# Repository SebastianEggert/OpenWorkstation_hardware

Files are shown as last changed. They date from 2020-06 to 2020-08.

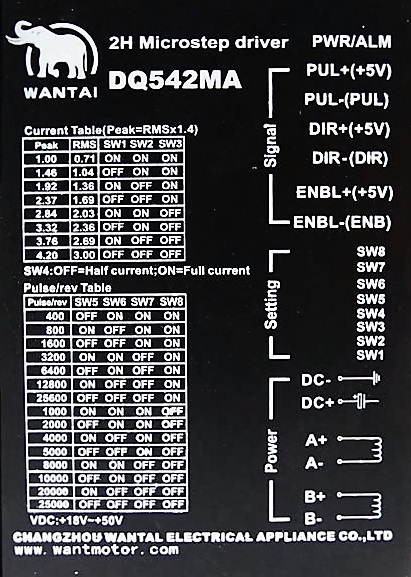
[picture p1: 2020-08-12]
OpenBuilds/SW2014 Parts Library 1/6 - Electronics/Decals/dq540ma_jpg.jpg

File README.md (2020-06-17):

## Hardware

The hardware section is divided into CAD files (SolidWorks) used to build the presented workstation (incl modules) and a parts library to accelerate the development process for new modules in the future.

All hardware files are available for the presented workstation:

 * [Assembled workstation](workstation)
 * [Pipetting module](modulePipetting)  
 * [Crosslinker module](moduleCrosslinker)
 * [Storage module](moduleStorage)
 * [Transport module](moduleTransport)
 * [Base frame](base-frame)

The following libraries are available to support users during the development of new module:

 * [Aluminium profiles](aluminium-profiles)
 * [Module frames](moduleFrame)
 * [OpenBuilds parts](OpenBuilds)

OpenBuilds provides additional support via their [SolidWorks part library](https://openbuilds.com/projectresources/solidworks-2014-parts-library.160/) and the uploaded models on [GrabCAD](https://grabcad.com/openbuilds-1/models).

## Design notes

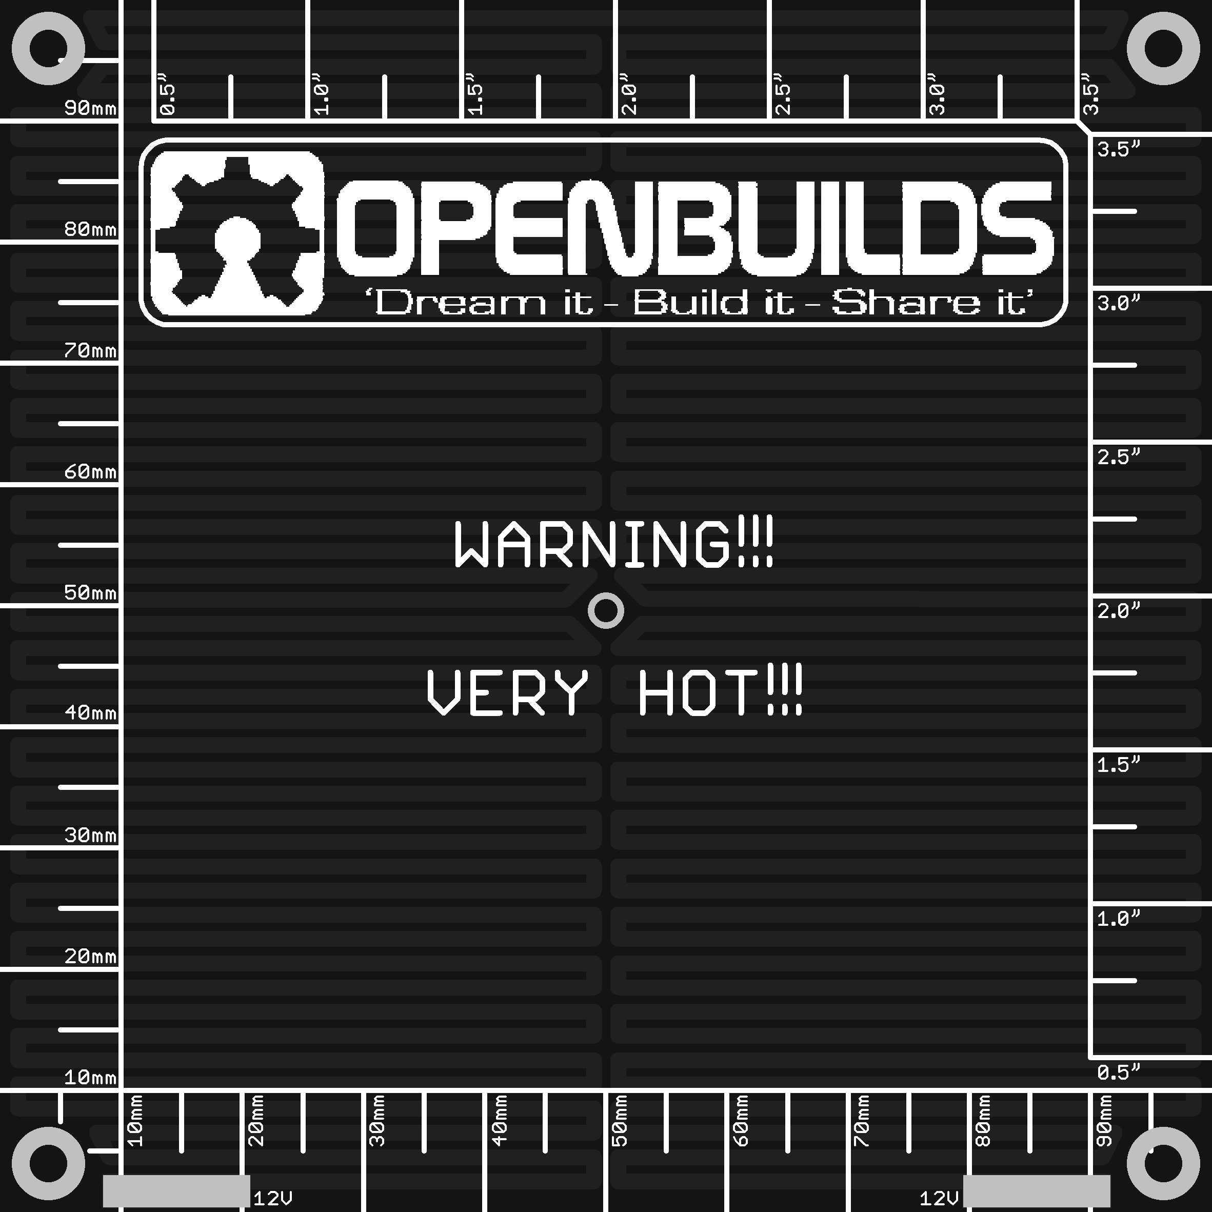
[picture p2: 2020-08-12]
OpenBuilds/SW2014 Parts Library 1/6 - Electronics/Decals/eagleUp_incendi_top_board.png

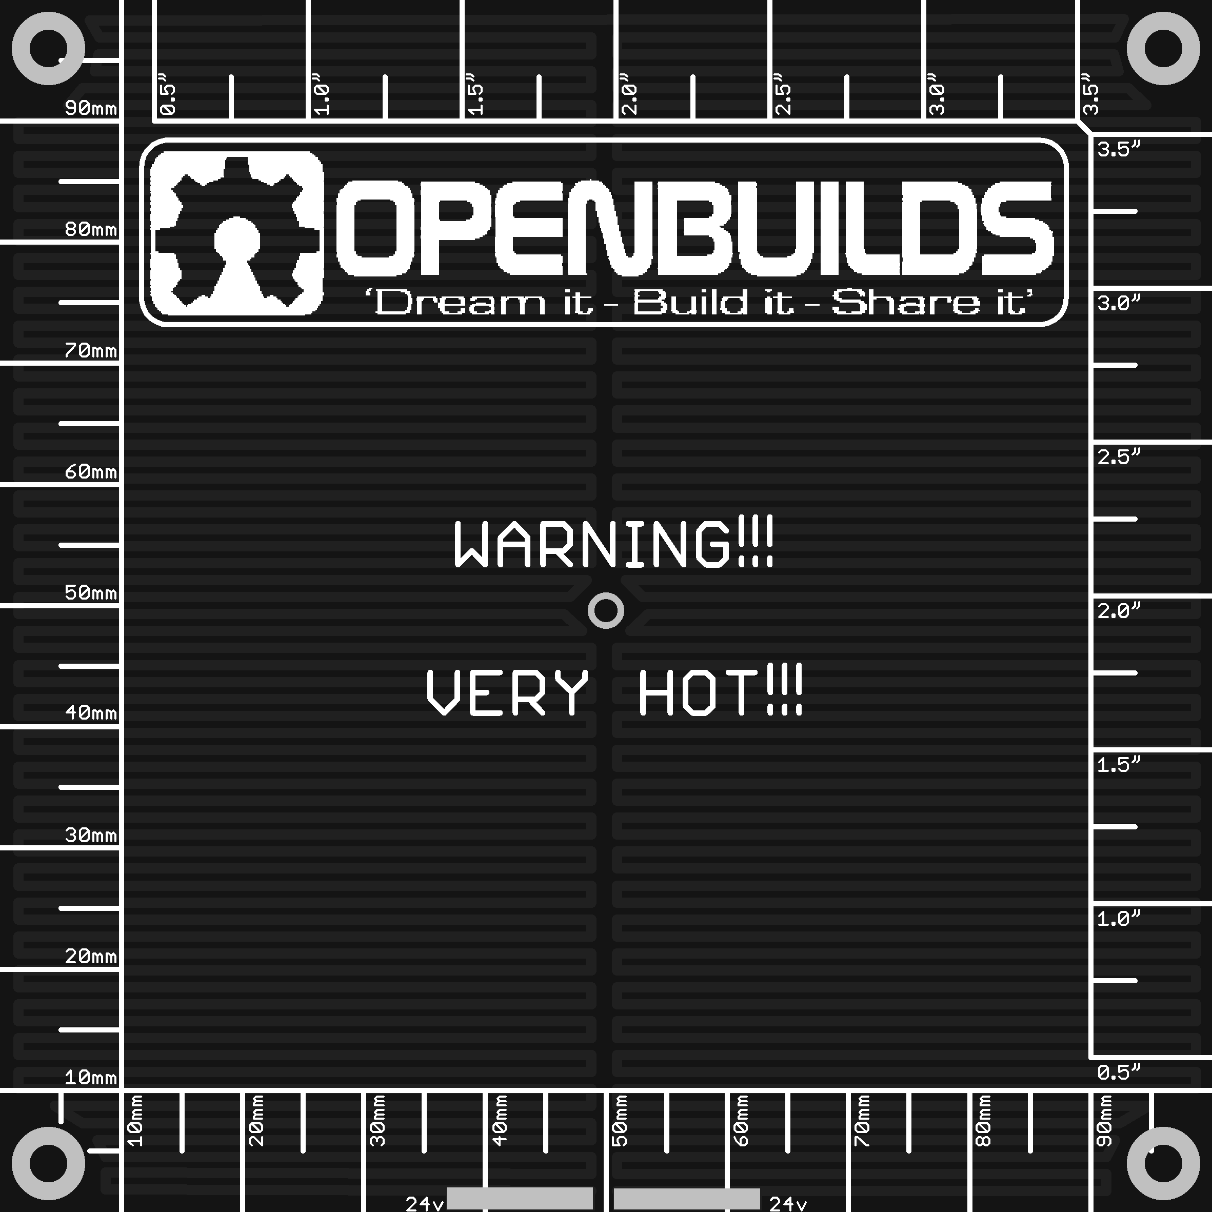
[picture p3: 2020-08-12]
OpenBuilds/SW2014 Parts Library 1/6 - Electronics/Decals/eagleUp_incendi_bottom_board.png

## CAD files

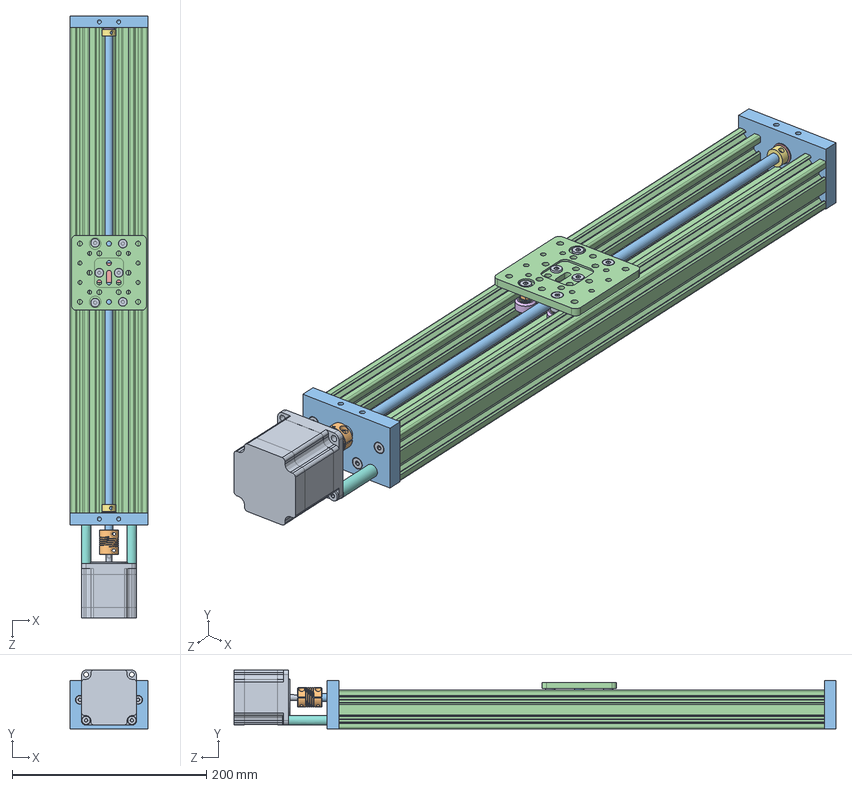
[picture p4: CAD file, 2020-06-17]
moduleCrosslinker/C-Beam_actuator_500mm.SLDASM
80.0 x 60.7 x 620.0 mm
Low Profile Screw M5 x 16
Nylon Insert Lock Nut M5 x 6
C-Beam End Mount x 2
C-Beam 40x80x500 Linear Rail
Ball Bearing 8 x 16 x 5 x 2
Shim Washer 8mm x 2
Lock Collar 8mm x 2
Aluminum Spacer 40mm x 2
Nema 23 Stepper Motor
Flexible Coupling 0.25in x 8mm
8mm leadscrew 540mm
C-Beam Gantry Plate
8mm Acme Nut Block
Xtreme Mini V Wheel x 4
Ball Bearing 5 x 10 x 4.2 x 8
Precision Shim 8 x 5 x 1 x 8
Aluminum Spacer 6mm x 2
Mini Eccentric Spacer 6mm x 2
Aluminum Spacer 3mm x 2

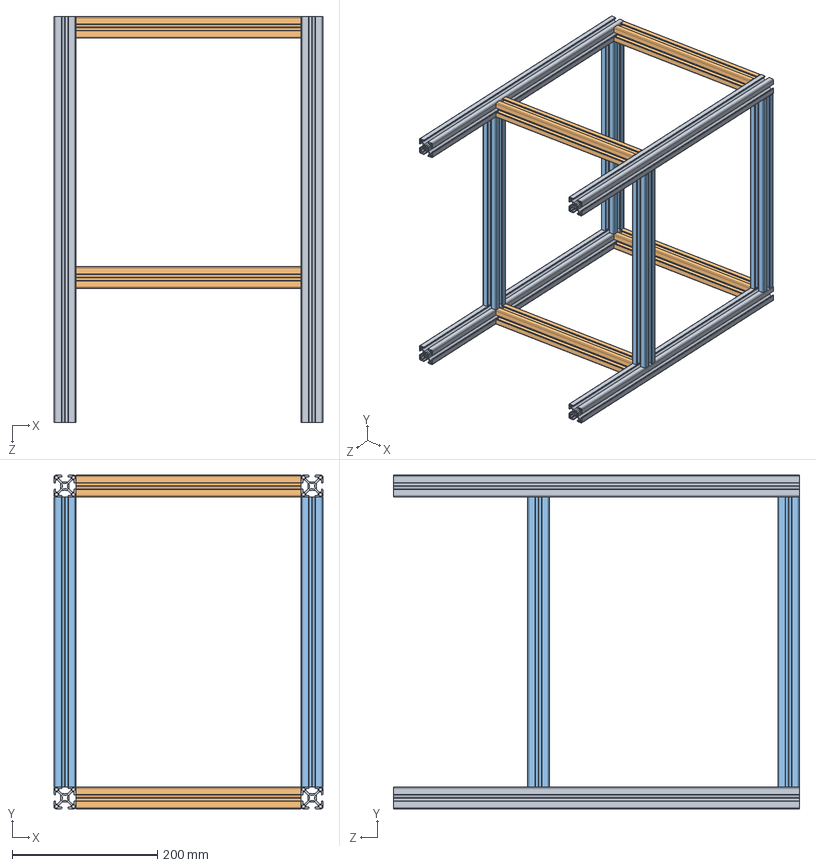
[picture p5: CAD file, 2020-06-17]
moduleFrame/module6_frame_v1.0.SLDASM
371.0 x 460.0 x 560.0 mm
profile_30x30mm_560mm x 4
Profile_30x30mm_311mm x 4
Profile_30x30mm_400mm x 4

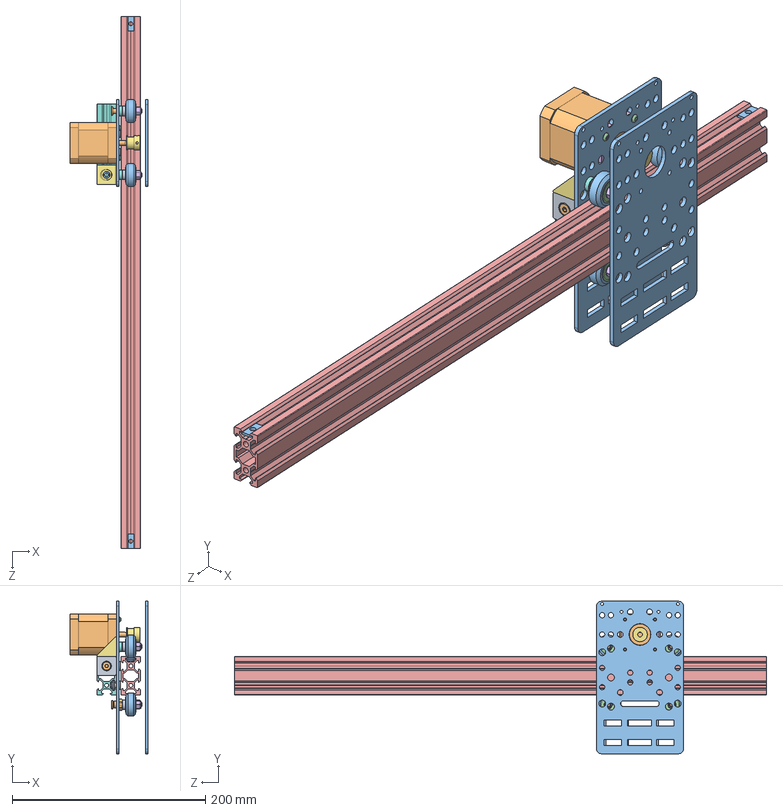
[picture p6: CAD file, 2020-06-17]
modulePipetting/Mini-V-Slot-Belt-Pinion-Actuator_550mm_v0.1.SLDASM
81.0 x 157.7 x 550.0 mm
Double Tee Nut x 2
Low Profile Screw M5 x 8
Button Head Socket Cap Screw M3 x 4
Tee Nut x 2
V-Slot 20x40x550 Linear Rail
Motor Mount Plate Nema 17
Nema 17 Stepper Motor
Solid V Wheel x 4
Ball Bearing 5 x 16 x 5 x 8
Precision Shim 10 x 5 x 1 x 4
Nylon Insert Lock Nut M5 x 4
GT2 Timing Pulley 20 Tooth
Aluminum Spacer .25in x 2
Aluminum Spacer .125in x 4
Eccentric Spacer 0.25in x 2
1002_Motor_Mount_Plate x 2

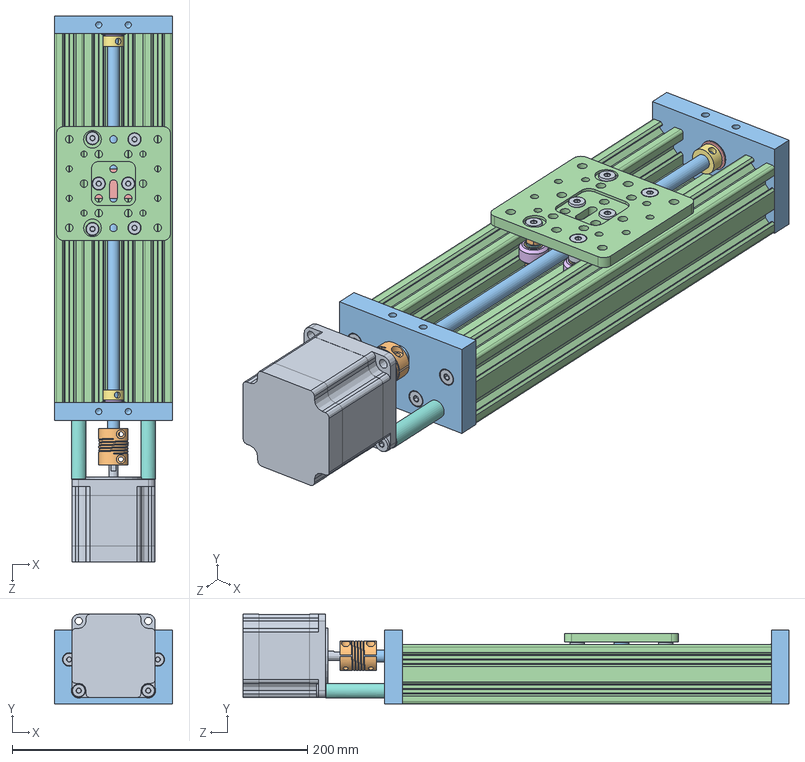
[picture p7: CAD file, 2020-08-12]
OpenBuilds/SW2014 Parts Library 1/Assemblies/C-Beam Linear Actuator/C-Beam Linear Actuator 250mm.SLDASM
80.0 x 60.7 x 370.0 mm
Low Profile Screw M5 x 16
Nylon Insert Lock Nut M5 x 6
C-Beam End Mount x 2
C-Beam 40x80x250 Linear Rail
Ball Bearing 8 x 16 x 5 x 2
Shim Washer 8mm x 2
Lock Collar 8mm x 2
Aluminum Spacer 40mm x 2
Nema 23 Stepper Motor
Flexible Coupling 0.25in x 8mm
8mm leadscrew 290mm
C-Beam Gantry Plate
8mm Acme Nut Block
Xtreme Mini V Wheel x 4
Ball Bearing 5 x 10 x 4.2 x 8
Precision Shim 8 x 5 x 1 x 8
Aluminum Spacer 6mm x 2
Mini Eccentric Spacer 6mm x 2
Aluminum Spacer 3mm x 2

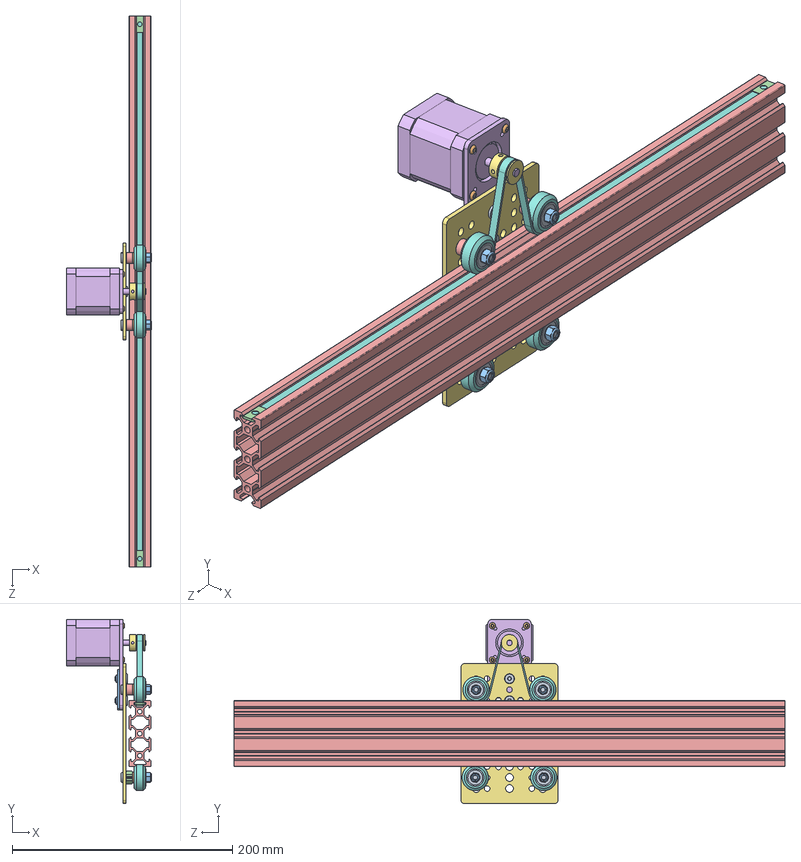
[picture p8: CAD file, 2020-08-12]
OpenBuilds/SW2014 Parts Library 1/Assemblies/V Slot Belt and Pinion Actuator/V Slot Belt and Pinion Actuator 500mm.SLDASM
77.0 x 167.2 x 500.0 mm
Low Profile Screw M5 x 6
Button Head Socket Cap Screw M3 x 4
Double Tee Nut
Tee Nut x 2
V-Slot 20x60x500 Linear Rail
Nema 17 Stepper Motor
V-Slot Gantry Plate 20-80mm
Solid V Wheel x 4
Ball Bearing 5 x 16 x 5 x 8
Precision Shim 10 x 5 x 1 x 8
Nylon Insert Lock Nut M5 x 4
Eccentric Spacer 6mm x 2
Aluminum Spacer 6mm x 2
Motor Mount Plate Nema 17
GT2 Timing Pulley 20 Tooth
GT2 Belt 585mm

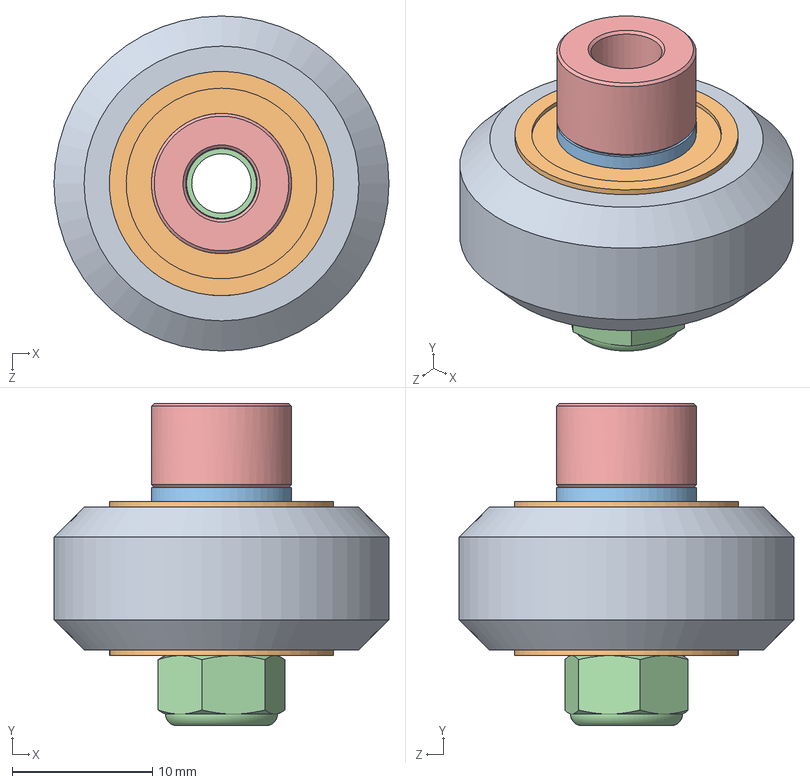
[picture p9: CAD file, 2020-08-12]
OpenBuilds/SW2014 Parts Library 1/Assemblies/Wheels/Xtreme V Wheel.SLDASM
23.9 x 23.0 x 23.9 mm
Xtreme Solid V Wheel
Ball Bearing 5 x 16 x 5 x 2
Precision Shim 10 x 5 x 1 x 2
Nylon Insert Lock Nut M5
Aluminum Spacer 6mm

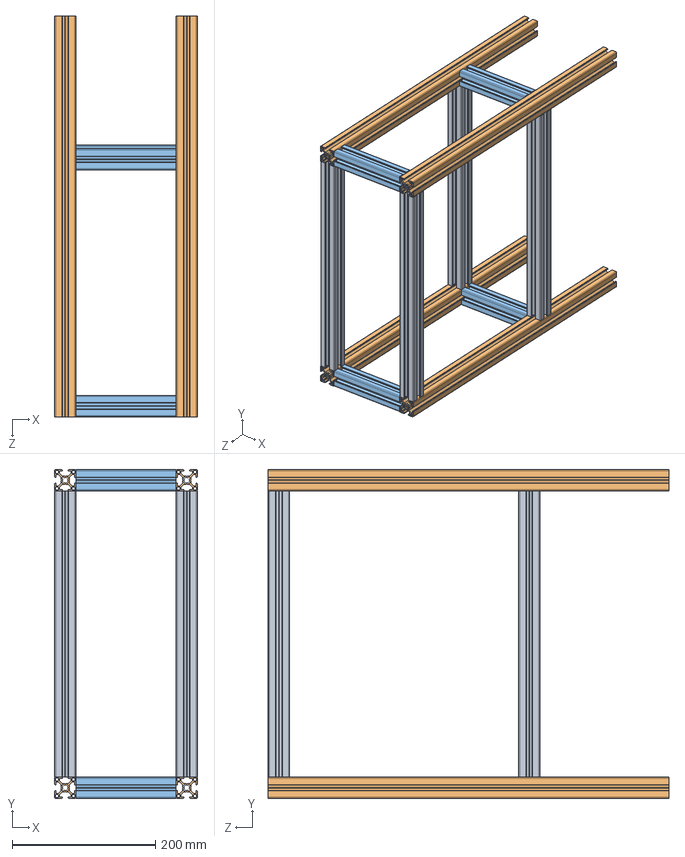
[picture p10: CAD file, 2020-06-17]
moduleFrame/module2_frame_v1.0.SLDASM
200.0 x 460.0 x 560.0 mm
Profile_30x30mm_400mm x 4
profile_30x30mm_560mm x 4
Profile_30x30mm_140mm x 4

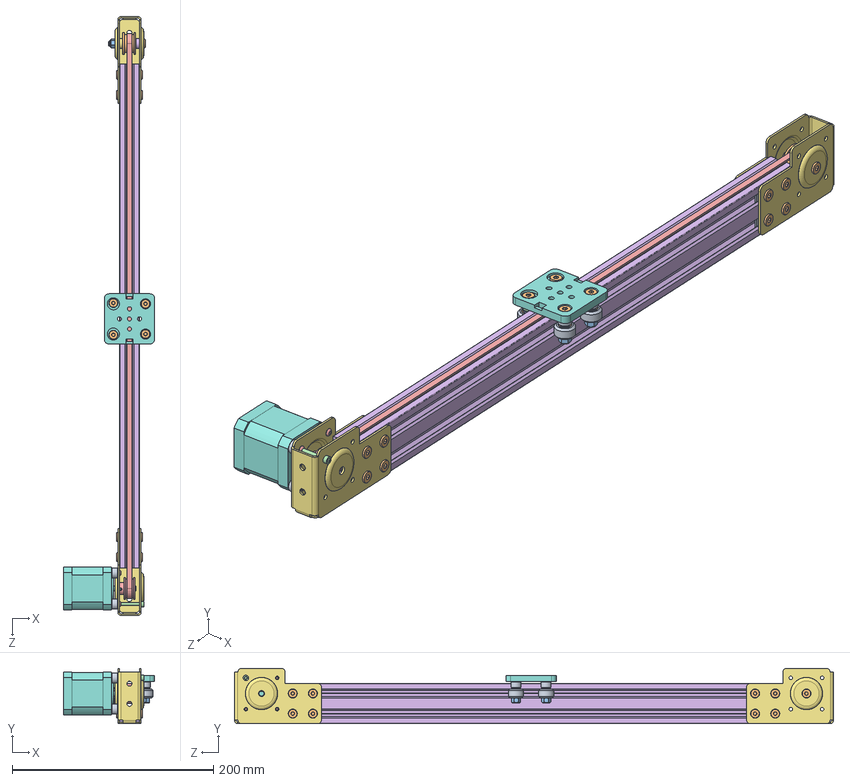
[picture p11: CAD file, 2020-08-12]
OpenBuilds/SW2014 Parts Library 1/Assemblies/Mini V Linear Actuator/Mini V Linear Actuator 500mm.SLDASM
90.6 x 54.9 x 594.7 mm
Double Tee Nut x 8
Low Profile Screw M5 x 21
Nylon Insert Lock Nut M5 x 5
Button Head Socket Cap Screw M3 x 4
V-Slot 20x40x500 Linear Rail
Linear Actuator End Mount x 2
Nema 17 Stepper Motor
Aluminum Spacer 6mm x 6
Smooth Idler Pulley Wheel
Ball Bearing 5 x 16 x 5 x 2
Nylon Spacer 0.125in
GT2 Timing Pulley 30 Tooth
Aluminum Spacer .25in
Aluminum Spacer .125in
Mini V Wheel Plate
Delrin Mini V Wheel x 4
Ball Bearing 5 x 10 x 4.2 x 8
Precision Shim 8 x 5 x 1 x 8
Mini Eccentric Spacer 6mm x 2
GT2 Belt 1140mm

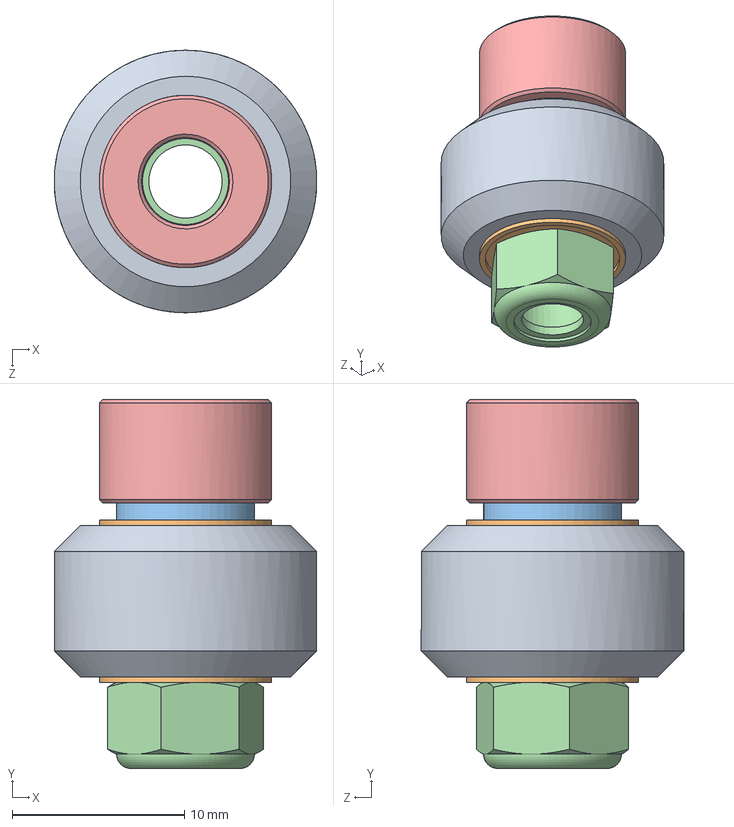
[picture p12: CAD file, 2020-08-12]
OpenBuilds/SW2014 Parts Library 1/Assemblies/Wheels/Xtreme Mini V Wheel.SLDASM
15.2 x 21.4 x 15.2 mm
Xtreme Mini V Wheel
Ball Bearing 5 x 10 x 4.2 x 2
Precision Shim 8 x 5 x 1 x 2
Nylon Insert Lock Nut M5
Aluminum Spacer 6mm

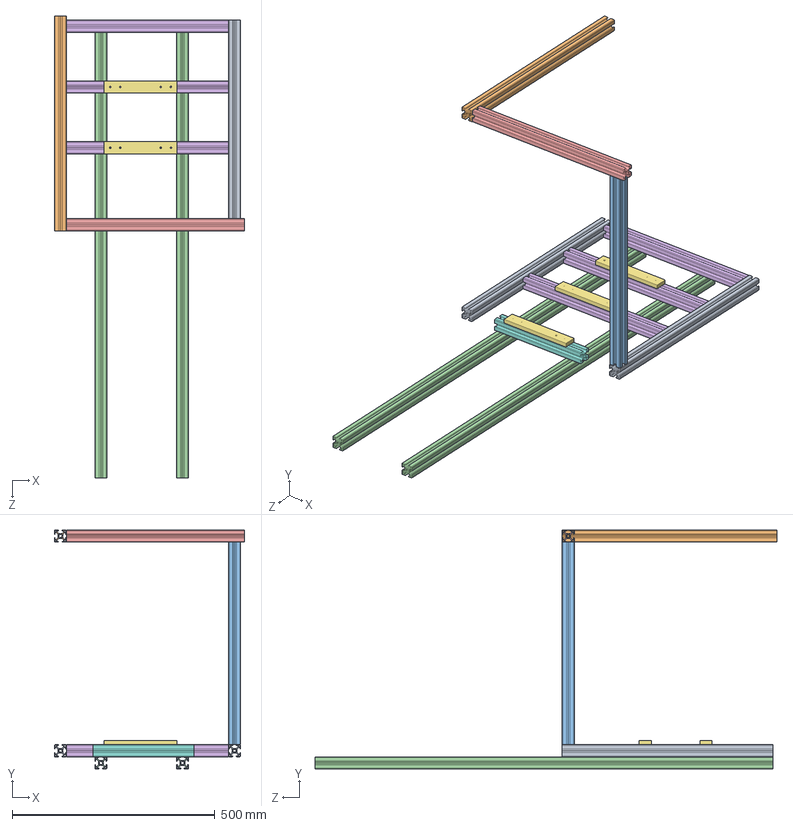
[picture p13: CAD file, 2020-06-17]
base-frame/frame_v1.3.SLDASM
470.0 x 590.0 x 1140.0 mm
profile_30x30mm_520mm x 2
Profile_30x30mm_1130mm x 2
Profile_30x30mm_400mm x 3
frame_spacer_v1.0 x 3
Profile_30x30mm_250mm

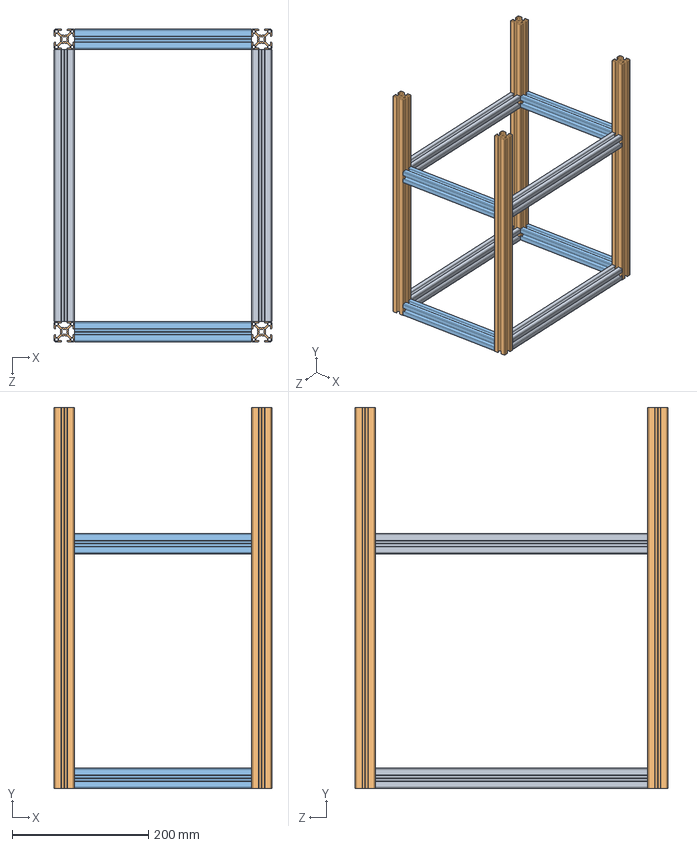
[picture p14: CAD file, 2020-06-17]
moduleFrame/module3_frame_v1.0.SLDASM
320.0 x 560.0 x 460.0 mm
Profile_30x30mm_400mm x 4
profile_30x30mm_560mm x 4
profile_30x30mm_260mm x 4

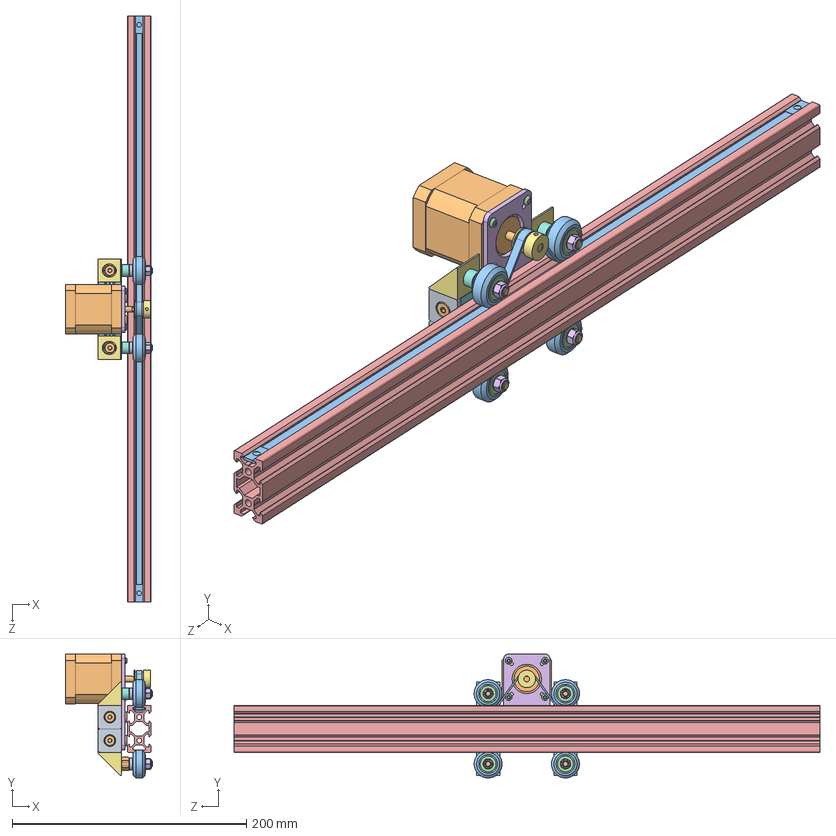
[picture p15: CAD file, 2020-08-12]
OpenBuilds/SW2014 Parts Library 1/Assemblies/V Slot Belt and Pinion Actuator/Mini V Slot Belt and Pinion Actuator 500mm.SLDASM
74.5 x 105.7 x 500.0 mm
Double Tee Nut x 2
Low Profile Screw M5 x 16
Tee Nut x 6
Button Head Socket Cap Screw M3 x 4
V-Slot 20x40x500 Linear Rail
Motor Mount Plate Nema 17
Black Angle Corner Connector x 4
V-Slot 20x40x80 Linear Rail
End Cap x 4
Nema 17 Stepper Motor
Solid V Wheel x 4
Ball Bearing 5 x 16 x 5 x 8
Precision Shim 10 x 5 x 1 x 4
Nylon Insert Lock Nut M5 x 4
GT2 Timing Pulley 20 Tooth
Aluminum Spacer .25in x 2
Aluminum Spacer .125in x 4
Eccentric Spacer 0.25in x 2
GT2 Belt 530mm

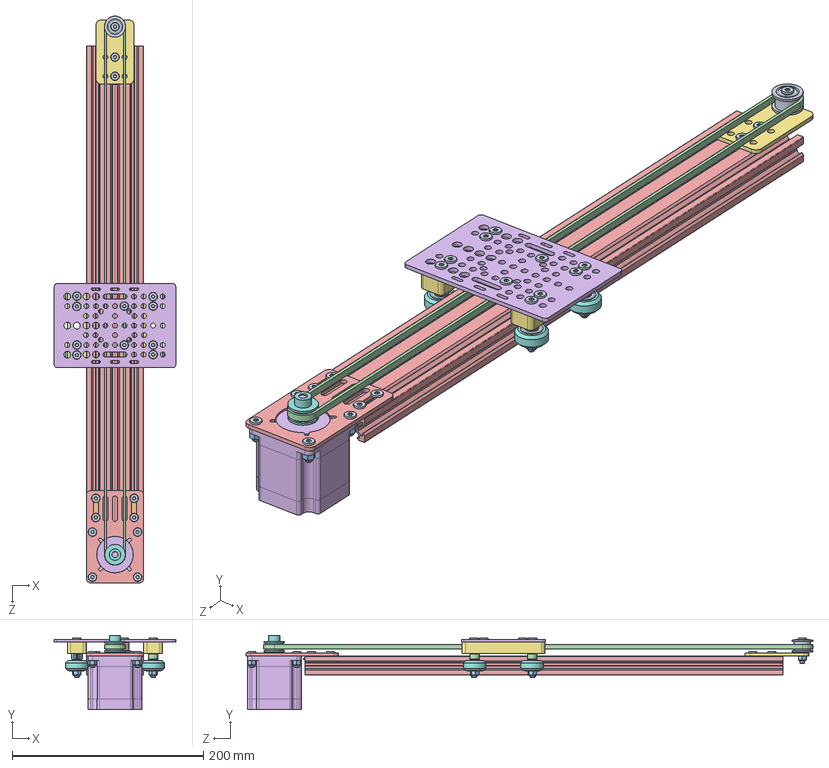
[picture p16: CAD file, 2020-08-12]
OpenBuilds/SW2014 Parts Library 1/Assemblies/V Slot Belt Driven Actuator/Nema 23 V Slot Belt Driven Actuator 500mm.SLDASM
127.0 x 77.6 x 592.7 mm
Low Profile Screw M5 x 21
Double Tee Nut x 3
Nylon Insert Lock Nut M5 x 9
Tee Nut x 2
V-Slot 20x60x500 Linear Rail
V-Slot Gantry Plate 20-80mm
Spacer Block x 2
Solid V Wheel x 4
Ball Bearing 5 x 16 x 5 x 10
Precision Shim 10 x 5 x 1 x 8
Eccentric Spacer 6mm x 2
Aluminum Spacer 6mm x 2
Motor Mount Plate Nema 23
Nema 23 Stepper Motor
Idler Pulley Plate
GT3 Timing Pulley 20 Tooth
Smooth Idler Pulley Wheel
Nylon Spacer 0.125in
Precision Shim 8 x 5 x 1
GT3 Belt 1160mm
Aluminum Spacer 9mm x 2

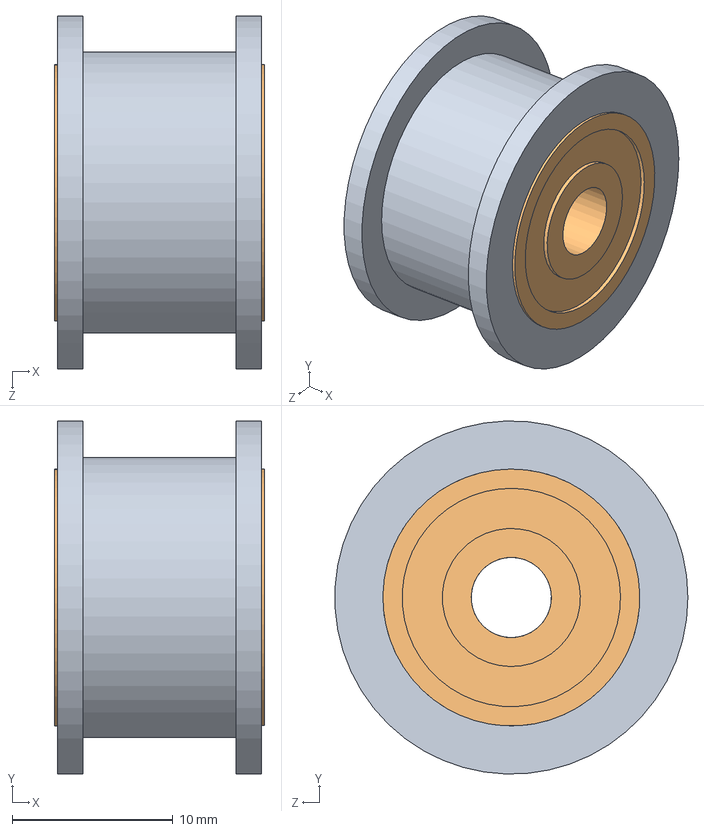
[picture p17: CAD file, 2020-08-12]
OpenBuilds/SW2014 Parts Library 1/Assemblies/Wheels/Smooth Idler.SLDASM
13.1 x 22.0 x 22.0 mm
Smooth Idler Pulley Wheel
Ball Bearing 5 x 16 x 5 x 2
Nylon Spacer 0.125in

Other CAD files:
workstation_SolidWorks/C-Beam_actuator_500mm.SLDASM
OpenBuilds/SW2014 Parts Library 1/Assemblies/V Slot Belt and Pinion Actuator/Solid V Wheel assy.SLDASM
OpenBuilds/SW2014 Parts Library 1/Assemblies/V Slot Belt Driven Actuator/Nema 17 V Slot Belt Driven Actuator 500mm.SLDASM
OpenBuilds/SW2014 Parts Library 1/Assemblies/Wheels/Delrin Mini V Wheel.SLDASM
OpenBuilds/STEP Parts Library 1/1 - Linear Rail/C-Beam 40x80x1000 Linear Rail.step
OpenBuilds/STEP Parts Library 1/1 - Linear Rail/C-Beam 40x80x250 Linear Rail.step
OpenBuilds/STEP Parts Library 1/1 - Linear Rail/C-Beam 40x80x500 Linear Rail.step
OpenBuilds/STEP Parts Library 1/1 - Linear Rail/Open Rail 1000mm.step
OpenBuilds/STEP Parts Library 1/1 - Linear Rail/Open Rail 1500mm.step
OpenBuilds/STEP Parts Library 1/1 - Linear Rail/Open Rail 500mm.step
OpenBuilds/STEP Parts Library 1/1 - Linear Rail/V-Slot 20x20x1000 Linear Rail.step
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

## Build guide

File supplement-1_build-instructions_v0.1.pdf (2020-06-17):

build_instructions_v0.1

## Step-by-Step Build Setup Guide

### Table of Contents

1 Base | 2
2 Transportation module | 2
3 Crosslinker module | 4
4 Storage module | 6
5 Electrical control box | 8

### 1 Base

The assembly process for the base is depicted in Figure 1.

Depending on the support (e.g. table, lab bench, biological safety cabinet, etc), select an appropriate solution to connect the workstation with the support. If the workstation is to be placed in a biological safety hood, keep the available height of the internal dimensions in mind.

Timing | 1 – 2 hours
Materials | 30x30mm aluminium profiles, screws (M5, M6), clamping angles, tee nuts for M5
and M6, laser cut parts (specifications are listed in the BOM)
Equipment | M5, M6 Allen key
Critical | cutting surface of aluminium profile should be straight
1| | Laser cut acrylic plates
2| | Position two aluminium profiles (30x30mm, 1540mm) next two each other
3| | Connect a grid base structure with four aluminium profiles (30x30mm, 400mm) to the base
with 29x29 clamping angles using M6x15 screws and M6 nuts

3| Attached spacer plates to the grid base structure using M5x15 screws and M5 nuts.

### 2 Transportation module

The assembly process for the transport module is depicted in Figure 1.

This module transports sample to the installed modules using a linear actuator and a sample holder. Depending on the overall length of the workstation, the length of the transportation module has to be selected to ensure that the sample can be transported to each module. The sample holder design can be optimized to the required experimental applications.

Timing | 1 day
Materials | linear actuators, M5 screws, corner brackets, tee nuts for M5, laser cut parts (specifications are listed in the BOM)
Equipment | M5 Allen key
Critical | cutting surface of aluminium profile should be straight

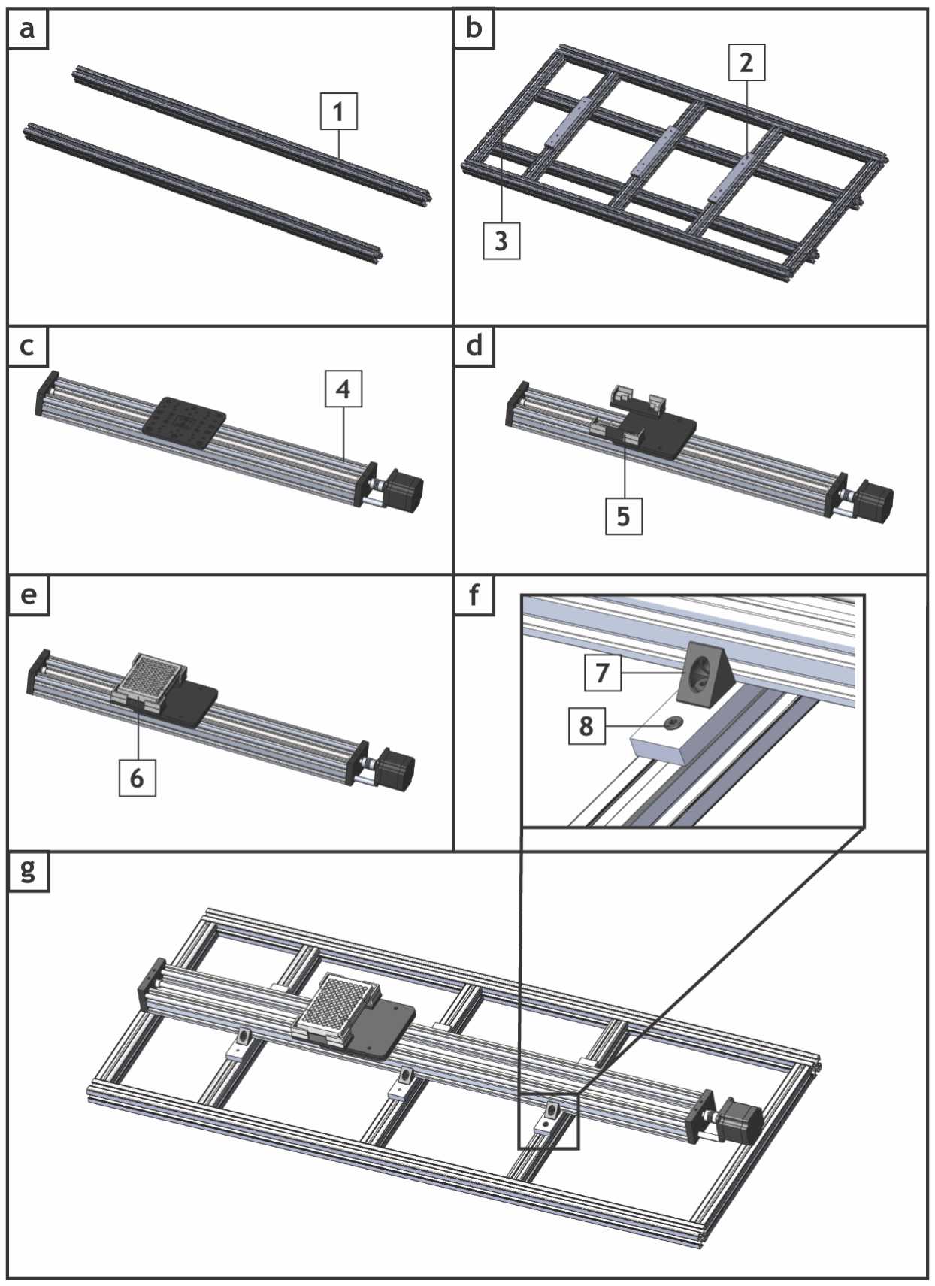
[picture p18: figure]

Figure 1: Assembly process for base (a,b), transport module (c-e), and connecting both (g). Parts: Two 30x30mm aluminium profiles (1), connecting struts (3) with spacer (2), linear stage (4) with holder (5) for well plate (6), and corner brackets (7) and screws (8).

1| | Laser cut acrylic plates as listed in the BOM
2| | Assemble the linear actuator (C-Beam Gantry Actuator) as instructed by OpenBuilds¹
3| | Assemble sample holder and attach to gantry plate using M5x15 screws
4| | Base und transportation module are connected using corner brackets.
5| | Y-direction of transportation module can be adjusted by positioning the plate spacers

### 3 Crosslinker module

The assembly process for the crosslinker module is depicted in Figure 2.

The crosslinker module provide photo-induced crosslinking and the ability to generate time gradients using a sliding mask. The LED panel provides a plug-and-play mode to enable fast modification and a customized solution.

Timing | 3 days
Materials | linear actuators for module as specified in BOM, 20x20mm and 30x30mm aluminium
profiles, screws (M3, M5, M6), clamping angles, tee nuts for M5 and M6, NEMA23 stepper motors, cable housing, laser cut parts
Equipment | M3, M5, M6 Allen key
Critical | cutting surface of aluminium profile should be straight
1| | Laser cut acrylic plates
2| | Assemble the two linear actuators as instructed by OpenBuilds²
3| | For the sliding mask, connect the sliding plates to the assembled 250mm linear actuator
using M5 screws

4| Attach enclosure to assembly using M5x15 screws and M5 tee nuts

1 https://www.youtube.com/watch?v=tLozVt_CjXQ 2 https://www.youtube.com/watch?v=tLozVt_CjXQ

5| | The module assembly starts by building the base frame using 30x30 mm profiles which are connected with 29x29 clamping angles using M6x15 screws and M6 nuts
6| | Attach right side wall to the base frame using M5x15 screw and M5 tee nuts
7| | Attach linear actuator to the back of the module, followed by putting in the back and front enclosure plate as well as the LED panel. The LED panel is attached to the gantry plate via two corner brackets
8| | Attach end stop holder at the top. Height and position can be customized/optimized later
9| | Connect left enclosure plate and missing profile
10| | Finish crosslinker assembly by attaching the sliding mask on the left side

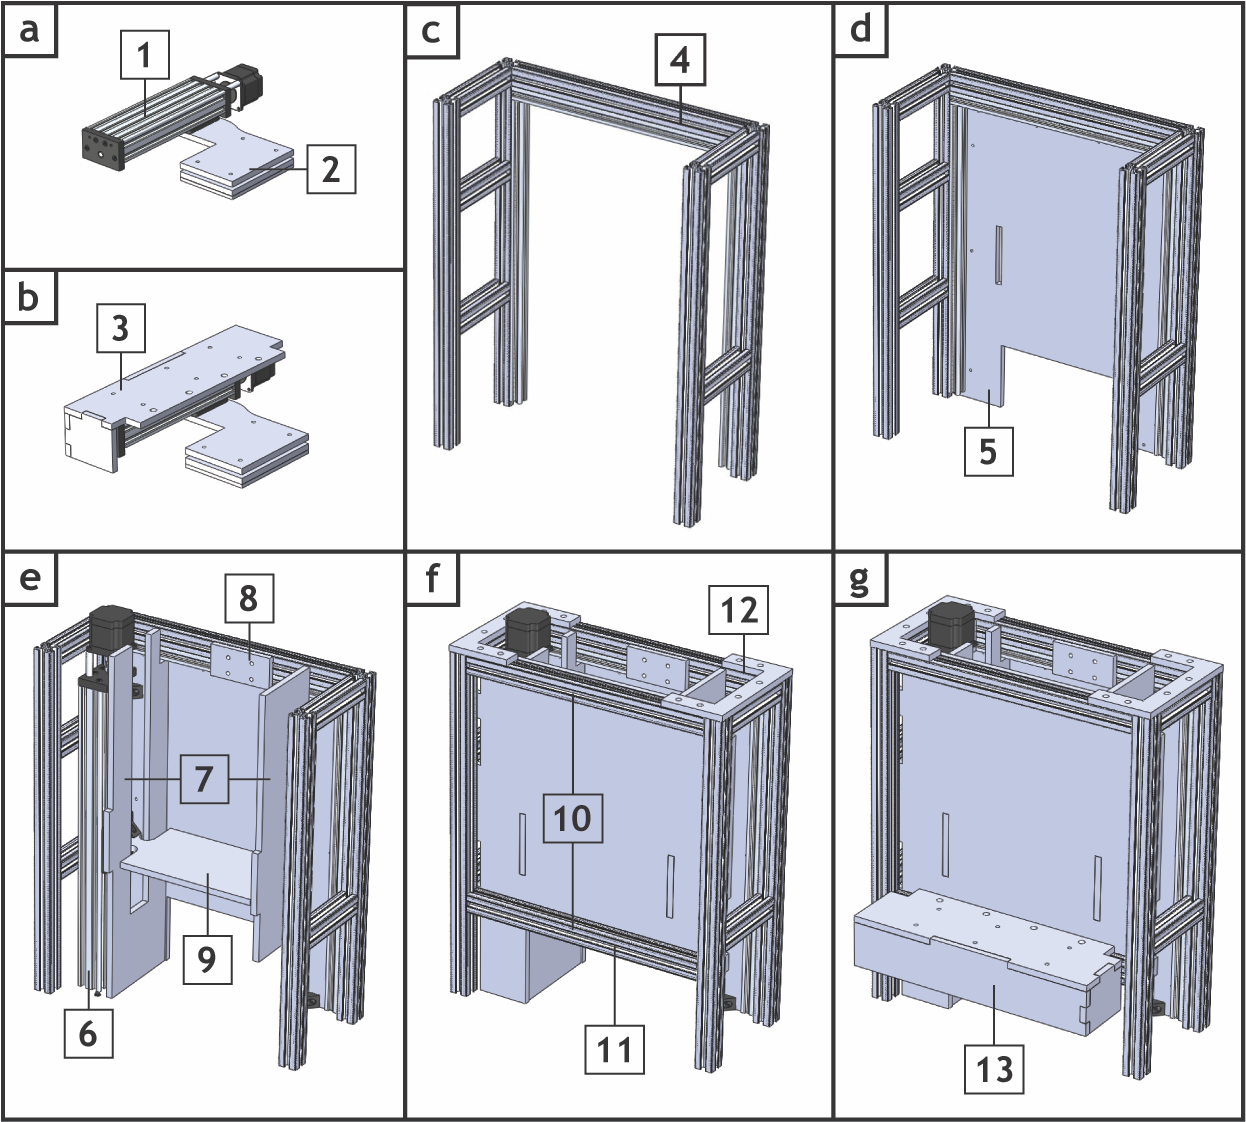
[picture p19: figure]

Figure 2: Assembly process for crosslinker module (a-g). Parts: linear stage (1) with mask (2) and enclosure (3), frame (4), side wall (5), linear stage (6), back wall (7), holder for end stop (8), LED panel (9), frame (10), side wall (11), connector plate (12), and gradient slider assembly (13).

### 4 Storage module

The assembly process for the storage module is depicted in Figure 3.

A storage module has been designed and developed to store well plates or to trash used well plates (e.g. after washing steps). Plates are stored within a rack unit and are positioned onto the transport module by a gripper unit.

Timing | 3 – 5 days
Materials | linear actuators for module as specified in BOM, 20x20mm and 30x30mm aluminium profiles, screws (M3, M5, M6), clamping angles, tee nuts for M5 and M6, NEMA23 stepper motors, cable housing, laser cut parts
Equipment | M3, M5, M6 Allen key
Critical | cutting surface of aluminium profile should be straight
1| | Laser cut acrylic plates as listed in the BOM
2| | Assemble the two linear actuators³
3| | Assembly gripper unit by connecting the 250mm linear belt & pinion actuator with the 20x20mm profile and the gripper plate. The length of the profile can be adjusted according to the depth of the storage module
4| | Assembly rack unit by attaching the four 20x20mm profiles to the laser cut plates which serve as holders for the well plate, and attach side plates (back, left, right)
5| | For the main storage module, connect 30x30mm aluminium profiles and insert holding frame for rack unit
6| | Connect 500mm linear actuator to the back of the module and attach gripper unit
7| | Attach missing profiles on the right side to the base frame

3 https://www.youtube.com/watch?v=tLozVt_CjXQ

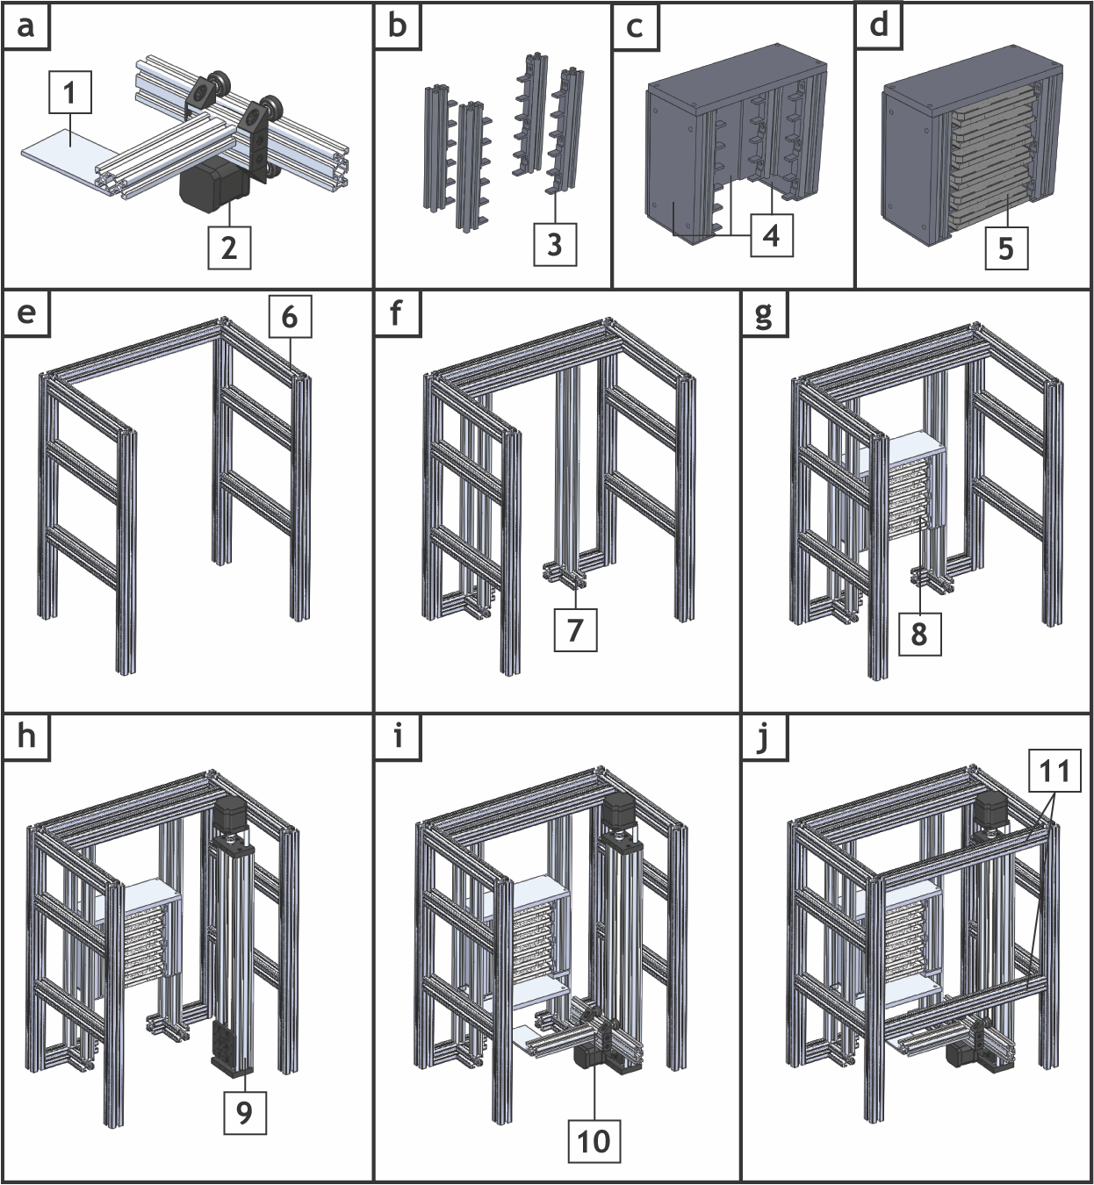
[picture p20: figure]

Figure 3: Assembly process for storage module (a-j). Parts: gripper plate (1), linear stage (2), shelf plates (3) for rack unit (4) to store well plates (5), main frame (6), profile frame for rack unit (7), rack unit (8), linear stage (9) with gripper unit (10), and enclosed frame (11).

### 5 Electrical control box

The main objective of this section is to provide a summary of the electrical work required to connect the stepper motors and end stops as well as to wire the smoothieboard and Arduino (Figure 4). For beginners, introductions to electricity⁴

, soldering⁵ and wiring⁶,7 are recommended before starting with the electrical assembly work. A dedicated control box was designed to comply with the requirements of the university’s Health and Safety guidelines. The main power circuit is a 12V circuit, which is considered as a low-voltage application in most countries. The number of the required components (e.g. control board) are selected based on the number of hardware modules and the required functionalities (e.g. valve).

Timing | 1 week for control box including electrical work
Materials | 2 and 4 core cable, solder, solder wick, heat shrink, ferrules crimper, laser cut plates
Equipment | fine (or flat tip) soldering iron, tweezers, optical microscope to inspect soldered connections, wire cutters, wire strippers, heat gun, multimeter
Caution | use approved or provided ferrules, since ferrule failure can result in wire creeping causing loose wires which may create short circuits
Critical | before starting with connecting the control board(s), familiarize yourself with the wiring diagram (see supplements); check with the Health and Safety department, if electrical work can be executed without a license or if qualified industrial electricians are required to connect the components
1| | If additional electrical components have been added into the control box, modify the control box geometry to accommodate all parts
2| | Laser cut acrylic plates for housing
3| | Drill threaded M3 or M5 holes into the base to attach electrical parts

4 https://learn.sparkfun.com/tutorials/electric-power/all
5 https://learn.adafruit.com/adafruit-guide-excellent-soldering 6 https://learn.sparkfun.com/tutorials/working-with-wire/all 7 https://learn.adafruit.com/wires-and-connections

4| Connect electrical parts to the base using M3 and M5 screws, starting with the power supply, control board, Arduino, valve, and breadboards

5| Start to connect electrical parts to each other according to the electrical circuit:

- Check Vin and GND connections to prevent a short circuit
- Use provided ferrules or connectors to connect wires
6| Connect main power to power supply, switch power on, and check if any LEDs of the smoothieboard are ON. If not, check troubleshooting list for power supply issues⁸
7| | Connect electrical parts of hardware modules to control board
7.1| | Connect the stepper motors to the control board.
- Locate A, A’, B and B’ wires from each of the stepper motors
- Insert wires to the stepper motor top connector according to the provided instructions⁹
- Continue until all stepper motors are connected
7.2| Connect the end stops to the control board
- Locate GND and Signal of each end stop
- Insert wires to the end stop top connector according to the provided instruction¹⁰
- Continue until all end stops are connected
7.3| Connect valve and LEDs to the control board
- Locate GND and Vin of each part
- Insert wires to MOSFET connectors
8| | Connect Arduino to the two temperature probes and two MOSFETs as shown in the electrical circuit schematics
9| | Optional: Install two fans, connected to the main power supply, for air cooling within the control box

8 http://smoothieware.org/troubleshooting#power-supply-problems
9 http://smoothieware.org/stepper-motors
10 http://smoothieware.org/endstops

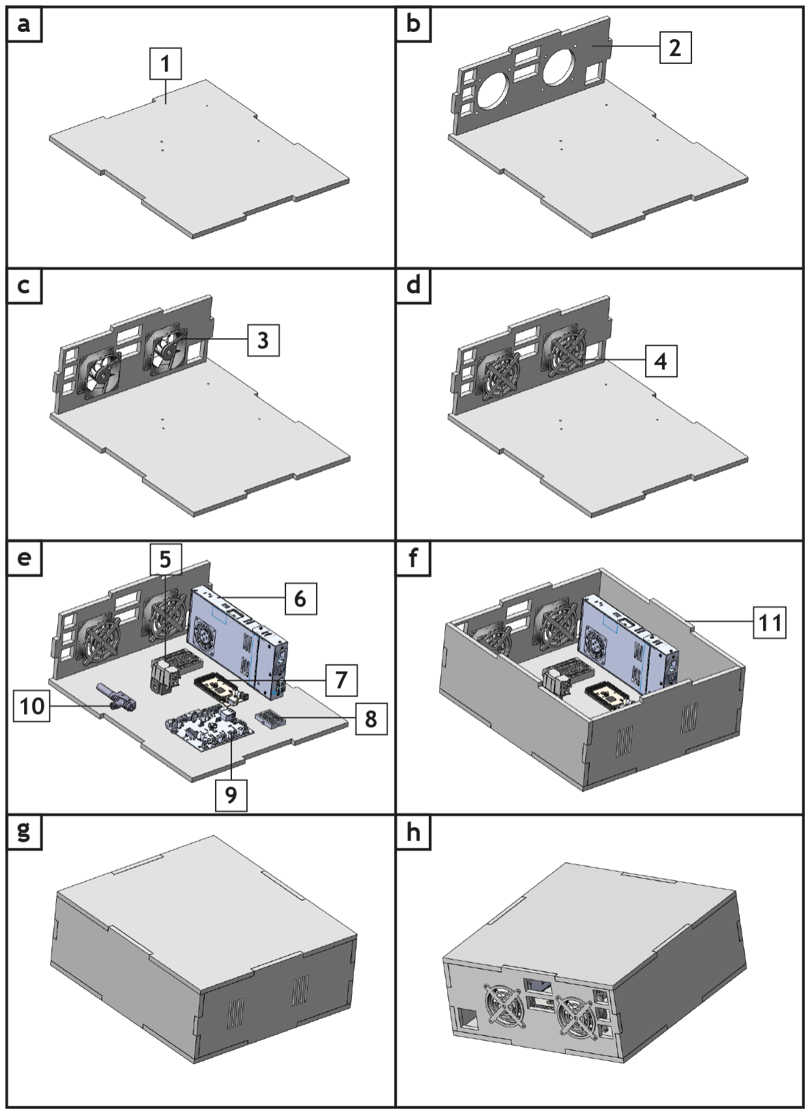
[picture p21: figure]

Figure 4: Assembly process for the control box (a-h): Parts: acrylic base plate (1), acrylic back wall (2) with fans (3) and fan grids (4), valve (5), power supply (6), Arduino MEGA, (7) bread board (8), smoothieboard (9), vacuum ejector (10), acrylic side walls (11).
